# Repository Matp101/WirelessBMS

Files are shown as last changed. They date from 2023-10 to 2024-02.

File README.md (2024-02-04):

# WirelessBMS

## Project Overview

The Wireless Battery Management System (BMS) is engineered to provide comprehensive monitoring and management of battery cells for electric vehicles (EVs), energy storage systems, and other applications requiring detailed battery oversight. It boasts features such as cell voltage and temperature monitoring, advanced balancing algorithms, state of charge (SOC) estimation, and robust communication capabilities for seamless integration with broader system architectures. The system utilizes an ESP32 module for the parent unit to leverage its powerful processing capabilities and connectivity options, and ESP8266 modules for child units to efficiently handle specific tasks and communicate with the parent unit.

### Features

- **Real-Time Monitoring**: Continuous measurement of voltage and temperature parameters for each cell.
- **Data Logging**: The system records detailed logs on an SD card for analysis and record-keeping.
- **Overcharge Protection**: The circuitry is designed to prevent cells from overcharging, a critical safety feature.
- **Mesh Networking**: Parent and child units communicate over a mesh network, enhancing reliability and range.
- **User Interface**: An website that shows key information for immediate visual feedback.
- **Expandability**: This design allows for the addition of more child units to the network as needed.

### Hardware Components

- **Parent Unit**:
  - **Microcontroller**: ESP32 module for processing and network connectivity.
  - **Sensors**: Current sensor (ACS712), voltage divider components for voltage sensing.
  - **Protection**: Overcharge protection circuitry.
  - **Communication**: WiFi mesh networking.
  - **Storage**: SD card slot for data logging and retrieval.
  - **Power Supply**: Voltage regulator and battery input connectors.
  - **PCB**: Parent PCB design for mounting and connecting all components.
  
- **Child Units**:
  - **Microcontroller**: ESP8266 for individual cell monitoring tasks.
  - **Sensors**: Dedicated voltage for precise monitoring.
  - **PCB**: Child PCB design tailored to fit and function within a distributed system.

### Installation

1. **Environment Setup**: Use PlatformIO for firmware development. It provides a comprehensive ecosystem for IoT development.
2. **Board Assembly**: Refer to the Bill of Materials (BOM) and PCB design files to assemble the boards.
3. **Firmware Flashing**: Use PlatformIO to compile and upload the firmware to the ESP32 and ESP8266 modules.

### Configuration

 - **Basic Configuration**: The config.h file outlines essential settings, including communication protocols, number of cells monitored, voltage thresholds, and temperature limits.
 - **Advanced Configuration**: For further customization, adv_config.h provides options for fine-tuning balancing thresholds, SOC calculation parameters, and enhanced communication settings.
 - **Battery Configuration**: Specific battery types and their parameters, such as capacity and nominal voltage, are defined within batteries.h.
 - **Sensor Calibration**: Adjust the sensor readings according to the specific characteristics of the used components to ensure accurate measurements.

### Usage

 - **Monitoring**: Utilizes the ESP32 and ESP8266 modules to continuously monitor cell voltages and temperatures, displaying this data via a user interface or transmitting it over a network.
 - **Balancing**: Implements cell balancing through balance.hpp, applying algorithms to maintain uniform charge levels across all cells, which is crucial for maximizing battery lifespan and efficiency.
 - **SOC Estimation**: Leverages fuelgauge.hpp for accurate estimation of the battery's State of Charge, employing algorithms adapted to the battery's specific configuration for precise monitoring and management.
  
### Documentation

- **Schematics**: Detailed schematics are provided for both parent and child units to assist in understanding and modifying the circuitry.
- **PCB Designs**: PCB layout files are included for reproduction or customization of the boards.
- **BOM**: The Bill of Materials lists all components needed for assembly.

### Gallery
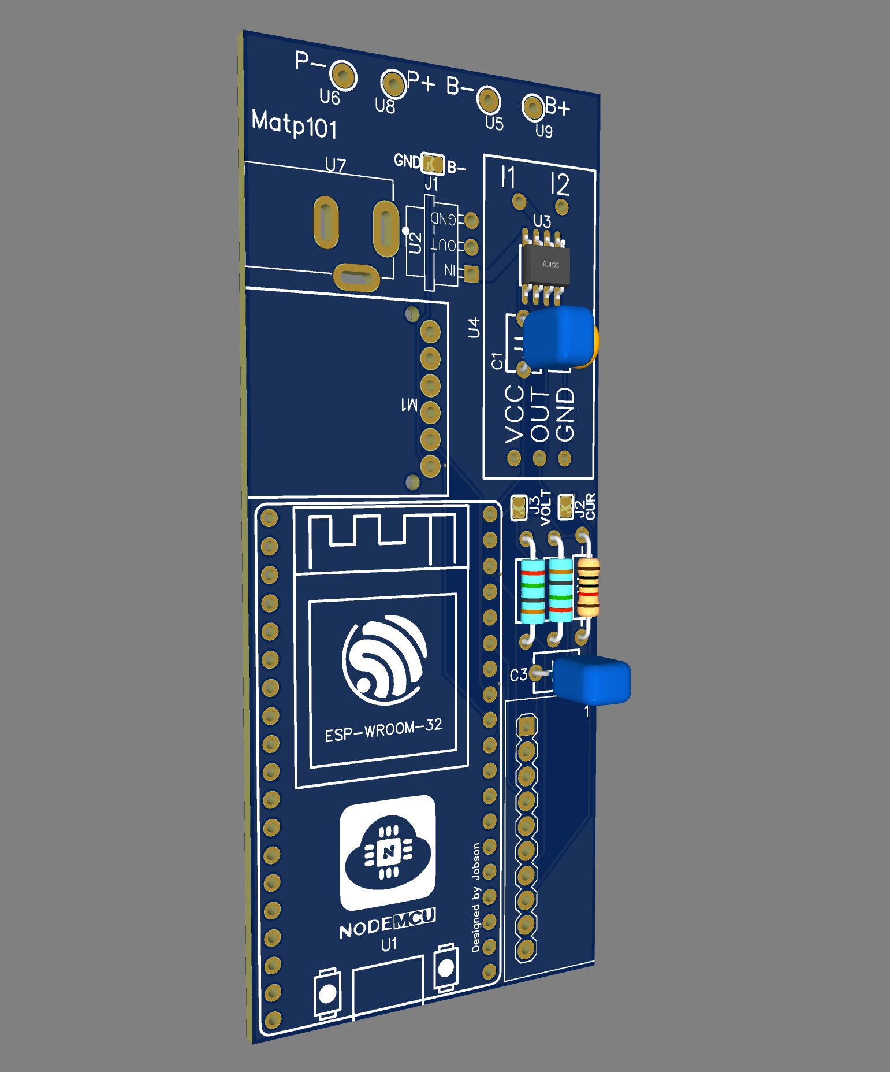
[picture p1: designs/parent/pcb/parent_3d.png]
Parent Unit

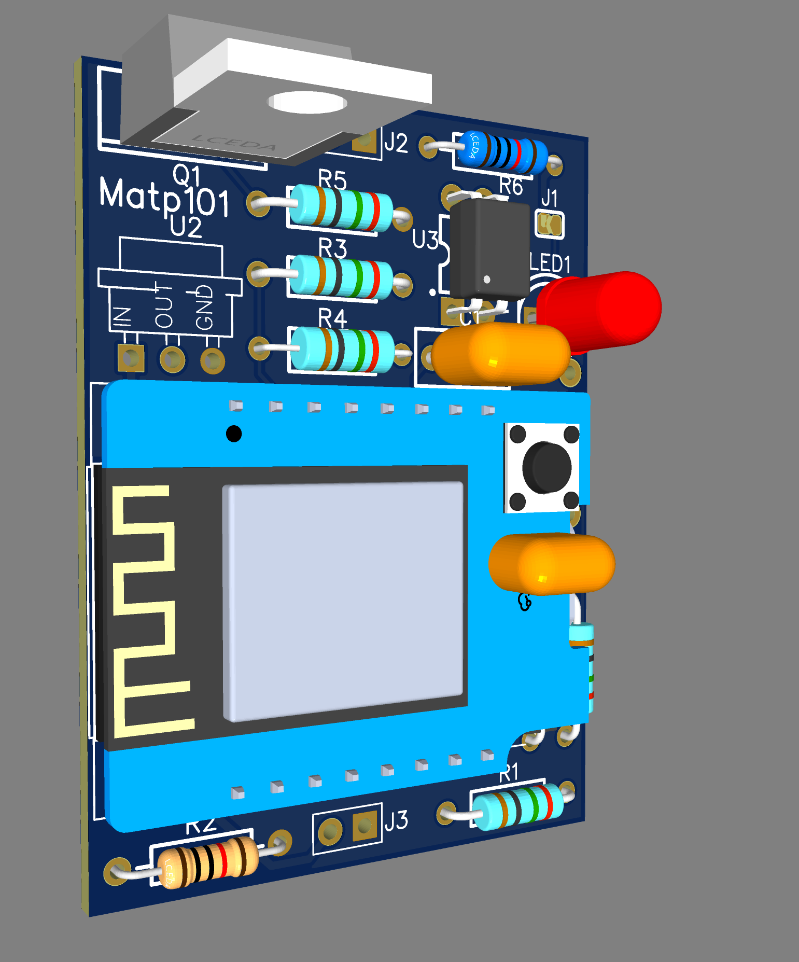
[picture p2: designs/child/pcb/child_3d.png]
Child Unit

Demo

---
## License

This work is licensed under the Creative Commons Attribution-NonCommercial-NoDerivs 4.0 International License. To view a copy of this license, visit [http://creativecommons.org/licenses/by-nc-nd/4.0/](https://creativecommons.org/licenses/by-nc-nd/4.0/) or send a letter to Creative Commons, PO Box 1866, Mountain View, CA 94042, USA.

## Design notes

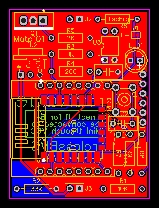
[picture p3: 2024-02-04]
designs/child/pcb/child_pcb.png

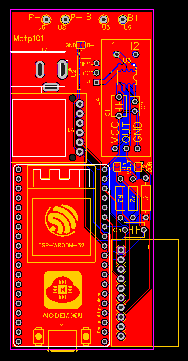
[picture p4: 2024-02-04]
designs/parent/pcb/parent_PCB.png

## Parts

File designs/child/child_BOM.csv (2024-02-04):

ID | Name | Designator | Footprint | Quantity | Manufacturer Part | Manufacturer | Supplier | Supplier Part | Price | Pins
1 | 100nF | C1,C2 | CAP-TH_L7.6-W3.8-P5.08-D0.51 | 2 | SR305C105KAR | Kyocera AVX | LCSC | C444741 | 0.629 | 2
2 | SOLDERJUMPERSMALL | J1 | SOLDERJUMPERSMALL | 1 |  |  |  |  |  | 2
3 | NO | J2,J3 | CONNECTOR_PINHEADER_2.54MM:PINHEADER_1X11_P_2.54MM | 2 | Female headerHDR1X8-2.54 | BOOMELE | LCSC | C27438 | 0.074 | 2
4 | FTDI | JP1 | FTDI | 1 |  |  |  |  |  | 6
5 | RESET | KEY1 | KEY-TH_4P-L6.0-W6.0-P4.50-LS7.5 | 1 | button6*6*8 | ReliaPro | LCSC | C59982 |  | 4
6 | LED-TH-3MM_R | LED1 | LED-TH_BD5.4-P2.54-FD_RED | 1 | LED-TH-3mm_R | null | LCSC | C9900003210 |  | 2
7 | IRLZ44PBF | Q1 | TO-220AB-3_L10.4-W4.6-P2.54-L | 1 | IRLZ44PBF-VB | VBsemi(微碧) | LCSC | C2680731 | 0.517 | 3
8 | 3.3kΩ | R1 | RES-TH_BD2.4-L6.3-P10.30-D0.6 | 1 | MFR-25FTE52-33K | YAGEO(国巨) | LCSC | C173005 | 0.012 | 2
9 | 10kΩ | R2 | RES-TH_BD2.2-L6.5-P10.50-D0.6 | 1 | MFR-25FTE52-100K | YAGEO(国巨) | LCSC | C172965 | 0.011 | 2
10 | 1kΩ | R3 | RES-TH_BD2.4-L6.3-P10.30-D0.6 | 1 | MFR50SFTE52-1K | YAGEO(国巨) | LCSC | C173143 | 0.02 | 2
11 | 200Ω | R4 | RES-TH_BD2.7-L6.2-P10.20-D0.4 | 1 | CR1/4W-200Ω±5%-ST52 | VO(翔胜) | LCSC | C2894669 | 0.003 | 2
12 | 2kΩ | R5 | RES-TH_BD2.4-L6.3-P10.30-D0.6 | 1 | MFR-25FTE52-2K | YAGEO(国巨) | LCSC | C172996 | 0.012 | 2
13 | 18Ω | R6 | RES-TH_BD2.3-L6.5-P10.50-D0.5 | 1 | CF1/4W-18Ω±5% T | CCO(千志电子) | LCSC | C120013 | 0.005 | 2
14 | 10kΩ | R7,R8,R9 | RES-TH_BD2.4-L6.3-P10.30-D0.6 | 3 | MFR-25FTE52-33K | YAGEO(国巨) | LCSC | C173005 | 0.012 | 2
15 | WEMOS_D1_MINI_PRO4 | U1 | DIP-16_WEMOS_D1_MINI_PRO4 | 1 | Wemos_D1_mini_Pro4 | null | LCSC | C2837266 |  | 16
16 | REG-AMS1117-3P-*#V | U2 | REG-AMS1117-3P#V | 1 |  |  |  |  |  | 3
17 | CYPC817D | U3 | DIP-4_L6.4-W4.6-P2.54-LS7.6-BL | 1 | CYPC817D | OCIC(卓睿科) | LCSC | C3018787 | 0.039 | 4
18 | ESP8266 | U4 | WIFIM-SMD_ESP-12F-ESP8266MOD | 1 | ESP8266 | null | LCSC | C9900003049 |  | 22

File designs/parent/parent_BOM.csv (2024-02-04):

ID | Name | Designator | Footprint | Quantity | Manufacturer Part | Manufacturer | Supplier | Supplier Part | Price | Pins
1 | ADC-4CH-ADS1115 | 1 | ADC-4CH-ADS1115 | 1 |  |  |  |  |  | 10
2 | 1nF | C1,C3 | CAP-TH_L5.5-W4.0-P5.00-D0.5 | 2 | Y5P102K2KV16CC0224 | KNSCHA(科尼盛) | LCSC | C2887266 | 0.034 | 2
3 | 100nF | C2 | CAP-TH_L5.0-W2.5-P2.54-D0.7 | 1 | CC1H104ZA1PD3F5O30MF | Dersonic(德尔创) | LCSC | C254067 | 0.02 | 2
4 | B- to GND | J1 | SOLDERJUMPERSMALL | 1 |  |  |  |  |  | 2
5 | A1 Connect | J2 | SOLDERJUMPERSMALL | 1 |  |  |  |  |  | 2
6 | A0 Connect | J3 | SOLDERJUMPERSMALL | 1 |  |  |  |  |  | 2
7 | MICRO-SD W 3D | M1 | MICRO-SD-MODULE | 1 |  |  |  |  |  | 6
8 | 10kΩ | R1 | RES-TH_BD2.2-L6.5-P10.50-D0.6 | 1 | MFR-25FTE52-100K | YAGEO(国巨) | LCSC | C172965 | 0.011 | 2
9 | 270kΩ | R2 | RES-TH_BD2.4-L6.3-P10.30-D0.6 | 1 | CFR-25JR-52-270K | YAGEO(国巨) | LCSC | C723609 | 0.006 | 2
10 | 160kΩ | R3 | RES-TH_BD2.4-L6.3-P10.30-D0.6 | 1 | CFR-25JR-52-270K | YAGEO(国巨) | LCSC | C723609 | 0.006 | 2
11 | NODEMCU-32SLUA | U1 | COMM-TH_NODEMCU-32SLUA | 1 | NodeMCU-32SLua | Ai-Thinker(安信可) | LCSC | C111436 |  | 38
12 | REG-AMS1117-3P-*#V | U2 | REG-AMS1117-3P#V | 1 |  |  |  |  |  | 3
13 | ACS712ELCTR-30A-T | U3 | SOIC-8_L5.0-W4.0-P1.27-LS6.0-BL | 1 | ACS712ELCTR-30A-T | ALLEGRO(美国埃戈罗) | LCSC | C9932 | 2.029 | 8
14 | ACS712AA | U4 | ACS712 | 1 |  |  |  |  |  | 5
15 | B- | U5 | 22-GAUGE | 1 |  |  |  |  |  | 1
16 | P- | U6 | 22-GAUGE | 1 |  |  |  |  |  | 1
17 | BARREL CONNECTOR | U7 | BARREL CONNECTOR | 1 |  |  |  |  |  | 3
18 | P+ | U8 | 22-GAUGE | 1 |  |  |  |  |  | 1
19 | B+ | U9 | 22-GAUGE | 1 |  |  |  |  |  | 1

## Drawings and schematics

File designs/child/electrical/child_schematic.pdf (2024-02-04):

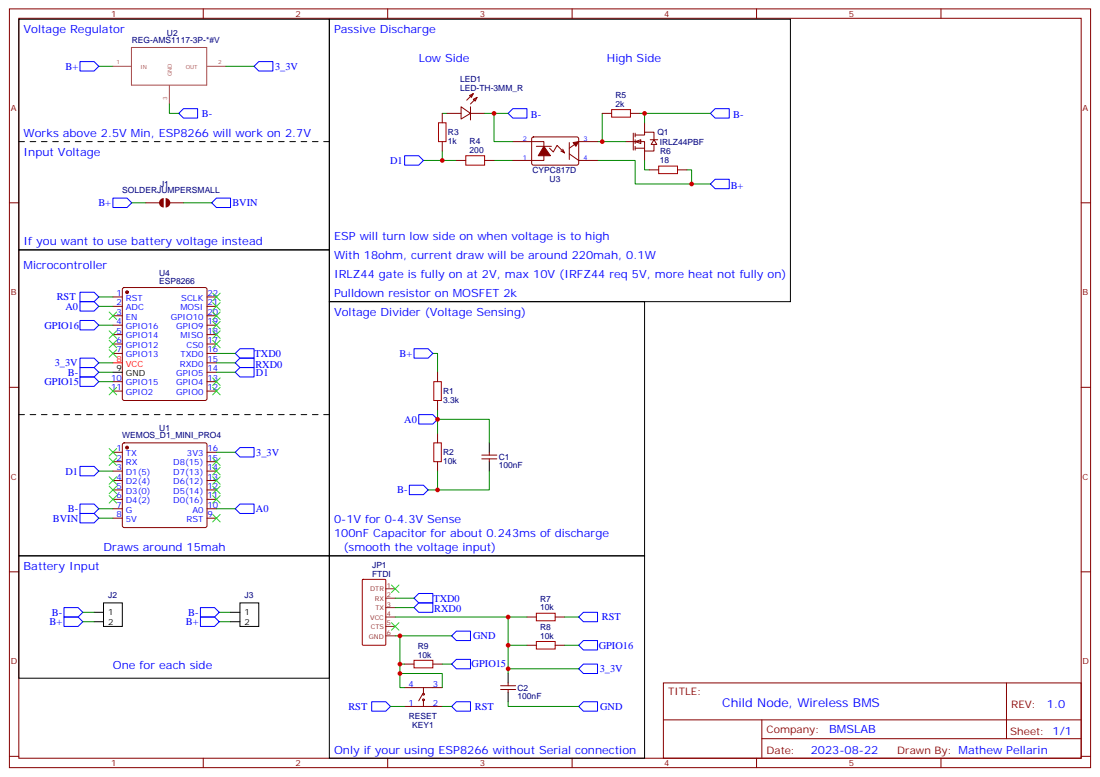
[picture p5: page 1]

Works above 2.5V Min, ESP8266 will work on 2.7V
Input Voltage

If you want to use battery voltage instead
Microcontroller

ESP will turn low side on when voltage is to high
With 18ohm, current draw will be around 220mah, 0.1W
IRLZ44 gate is fully on at 2V, max 10V (IRFZ44 req 5V, more heat not fully on)
Pulldown resistor on MOSFET 2k
Voltage Divider (Voltage Sensing)

One for each side

Only if your using ESP8266 without Serial connection

Drawn By: Mathew Pellarin

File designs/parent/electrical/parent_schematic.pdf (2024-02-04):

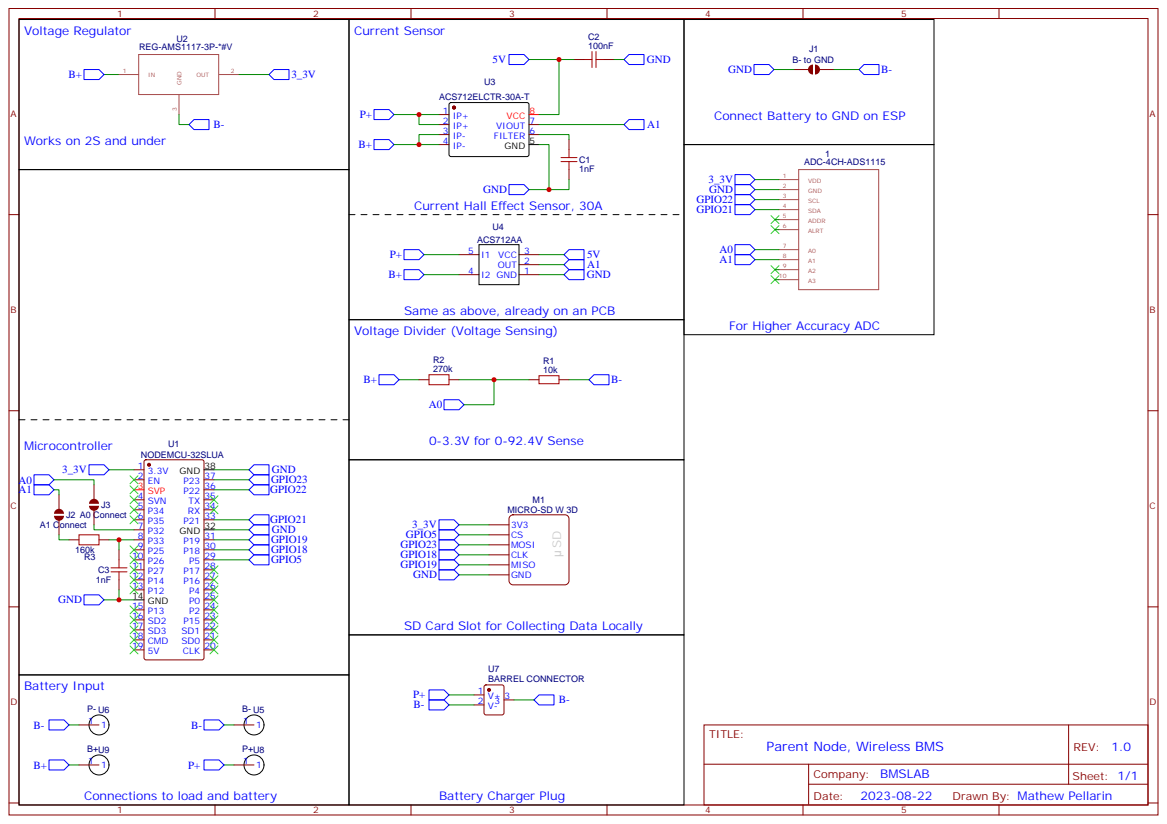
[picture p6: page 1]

Works on 2S and under

Connect Battery to GND on ESP

Current Hall Effect Sensor, 30A

Same as above, already on an PCB

For Higher Accuracy ADC

Voltage Divider (Voltage Sensing)

SD Card Slot for Collecting Data Locally

Connections to load and battery

Drawn By: Mathew Pellarin

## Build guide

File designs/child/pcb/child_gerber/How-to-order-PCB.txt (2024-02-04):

How to Order PCB

Please refer to:
https://docs.easyeda.com/en/PCB/Order-PCB

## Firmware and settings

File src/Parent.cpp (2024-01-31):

// TODO:
//  Add on connection, set cell number (save node_id to eeprom, save calibration)
//  SDcard logging
//  https://randomnerdtutorials.com/esp32-microsd-card-arduino/

#ifdef PARENT
#include <Arduino.h>
#include <painlessMesh.h>
#include <ArduinoJson.h>
#include <ACS712.h>
#include <ESPAsyncWebServer.h>
#include <fuelgauge.hpp>

#include <SPI.h>
#include <SD.h>

#include "batteries.h"
#include "config.h"
#include "adv_config.h"

#if defined(DEBUG_SERIAL) && !defined(PRINTF)
#define PRINTF(...)             \
  {                             \
    Serial.printf(__VA_ARGS__); \
  }
#endif
#if defined(DEBUG_LED) && defined(LED_BUILTIN)
#define LED LED_BUILTIN
#endif

// Parent 
struct Parent
{
  float voltage;
  float voltage_nodes;
  float current;
  float soc;
  float tt;
};

// Prototypes
void sendMessage();
void receivedCallback(uint32_t from, String &msg);
void newConnectionCallback(uint32_t nodeId);
void changedConnectionCallback();
void nodeTimeAdjustedCallback(int32_t offset);
void delayReceivedCallback(uint32_t from, int32_t delay);
float getVoltageNodes();
float getVoltageRead();
float getCurrent();
float getSOC();
float getTT();
int calibrateCurrent();
void updateValues();
void webserver();

Parent parent;

Scheduler userScheduler; // to control your personal task
painlessMesh mesh;

bool calc_delay = false;
SimpleList<uint32_t> nodes;

IPAddress getlocalIP();
AsyncWebServer server(80);
IPAddress myAPIP(IP_ADDRESS);

ACS712 current_sensor(CURRENT_SENSOR_TYPE, CURRENT_SENSOR_PIN, 3.3, 4095);
FuelGauge fuel_gauge(BATTERY_NOMINAL_CAPACITY, BATTERY_INTERNAL_RESISTANCE, BATTERY_MAX_VOLTAGE, BATTERY_LOAD_CURRENT, 4);

std::map<uint32_t, String> nodeData; // NodeID -> JSON data

bool fuel_gauge_initialized = false;

#ifdef DEBUG_LED
// Task to blink the number of nodes
Task blinkNoNodes;
bool onFlag = false;
#endif

void setup()
{
  Serial.begin(115200);
#ifdef DEBUG_LED
  pinMode(LED, OUTPUT);
#endif

  // setup wifi mesh
  mesh.setDebugMsgTypes(ERROR | STARTUP | DEBUG);
  mesh.init(MESH_SSID, MESH_PASSWORD, &userScheduler, MESH_PORT, WIFI_AP_STA, 6);
  mesh.onReceive(&receivedCallback);

  mesh.stationManual(STATION_SSID, STATION_PASSWORD);
  mesh.setHostname(HOSTNAME);

  mesh.onNewConnection(&newConnectionCallback);
  mesh.onChangedConnections(&changedConnectionCallback);
  mesh.onNodeTimeAdjusted(&nodeTimeAdjustedCallback);
  mesh.onNodeDelayReceived(&delayReceivedCallback);
  mesh.setRoot(true);
  mesh.setContainsRoot(true);

  myAPIP = IPAddress(mesh.getAPIP());
  PRINTF("My API IP is %d.%d.%d.%d\n", myAPIP[0], myAPIP[1], myAPIP[2], myAPIP[3]);

  // userScheduler.addTask( taskSendMessage );
  // taskSendMessage.enable();

#ifdef DEBUG_LED
  blinkNoNodes.set(BLINK_PERIOD, (mesh.getNodeList().size() + 1) * 2, []()
                   {
      // If on, switch off, else switch on
      if (onFlag)
        onFlag = false;
      else
        onFlag = true;
      blinkNoNodes.delay(BLINK_DURATION);

      if (blinkNoNodes.isLastIteration()) {
        // Finished blinking. Reset task for next run 
        // blink number of nodes (including this node) times
        blinkNoNodes.setIterations((mesh.getNodeList().size() + 1) * 2);
        // Calculate delay based on current mesh time and BLINK_PERIOD
        // This results in blinks between nodes being synced
        blinkNoNodes.enableDelayed(BLINK_PERIOD - 
            (mesh.getNodeTime() % (BLINK_PERIOD*1000))/1000);
      } });
  userScheduler.addTask(blinkNoNodes);
  blinkNoNodes.enable();

  PRINTF("Starting Webserver")
  webserver();
  server.begin();

#endif

}


static unsigned long lastUpdate = 0;
void loop()
{
  // mesh connected
  mesh.update();

  if(!fuel_gauge_initialized && getCurrent() == 0.0f){
    PRINTF("Initializing Fuel Gauge\n");
    fuel_gauge.initialize(getCurrent(), getVoltageNodes(), &parent.soc, &parent.tt);
    fuel_gauge_initialized = true;
  }

  //update current, voltage, soc, tt
  if (millis() - lastUpdate > 1000)
  {
    lastUpdate = millis();
    updateValues();
  }

  // Send JSON to Serial
  #ifdef JSON_SERIAL
  if (millis() - lastUpdate > JSON_SERIAL_INTERVAL)
  {
    lastUpdate = millis();
    PRINTF(toJson().c_str());
  }
  #endif

  // Blink LED if mesh is connected
#ifdef DEBUG_LED
  digitalWrite(LED, !onFlag);
#endif
}

// Send back to main node all the details about itself, if main node yet then broadcast
/*
If main esp is talking to this node
 info:cell == 0
 info:node_id == NodeId
 set:callibration_offset == int
 set:callibration_scale == int
 set:cell == int
 set:balance == bool
*/
void sendMessage()
{
  DynamicJsonDocument doc(256);
  doc["info"]["serial_number"] = SERIAL_NUMBER;
  doc["info"]["cell"] = 0;
  // doc["info"]["node_id"] =

  String jsonString;
  serializeJson(doc, jsonString);

  mesh.sendBroadcast(jsonString);
  // mesh.sendSingle(node, jsonString);
  if (calc_delay)
  {
    SimpleList<uint32_t>::iterator node = nodes.begin();
    while (node != nodes.end())
    {
      mesh.startDelayMeas(*node);
      node++;
    }
    calc_delay = false;
  }

#if DEBUG_SERIAL >= 1
  PRINTF("Sending message: %s\n", jsonString.c_str());
#endif
}

/*
  doc["info"]["serial_number"] = SERIAL_NUMBER;
  doc["info"]["cell"] = cell_num;
  doc["info"]["node_id"] = mesh.getNodeId();
  doc["info"]["free_mem"] = ESP.getFreeHeap();
  doc["cell"]["voltage"] = cell_voltage.getLastVoltage();   // make sure to get last voltage rather than update current due to passive balancing
  doc["cell"]["voltage_raw"] = cell_voltage.readRaw();
  doc["cell"]["voltage_calibration_offset"] = cell_voltage.getCalibrationOffset();
  doc["cell"]["voltage_calibration_scale"] = cell_voltage.getCalibrationScale();
  doc["balance"]["state"] = balancSer.getState();
*/
void receivedCallback(uint32_t from, String &msg)
{

#if DEBUG_SERIAL >= 2
  PRINTF("Received from %u msg=%s\n", from, msg.c_str());
#endif
  nodeData[from] = msg;
}

void newConnectionCallback(uint32_t nodeId)
{
#ifdef DEBUG_LED
  // Reset blink task
  onFlag = false;
  blinkNoNodes.setIterations((mesh.getNodeList().size() + 1) * 2);
  blinkNoNodes.enableDelayed(BLINK_PERIOD - (mesh.getNodeTime() % (BLINK_PERIOD * 1000)) / 1000);
#endif

#if DEBUG_SERIAL >= 1
  PRINTF("=================\nNew Connection\n");
  PRINTF("nodeId = %u\n", nodeId);
  PRINTF("%s\n", mesh.subConnectionJson(true).c_str());
  PRINTF("=================\n");
#endif
}

void changedConnectionCallback()
{

  nodes = mesh.getNodeList();

#ifdef DEBUG_LED
  // Reset blink task
  onFlag = false;
  blinkNoNodes.setIterations((mesh.getNodeList().size() + 1) * 2);
  blinkNoNodes.enableDelayed(BLINK_PERIOD - (mesh.getNodeTime() % (BLINK_PERIOD * 1000)) / 1000);
#endif

#if DEBUG_SERIAL >= 1
  // List all nodes
  PRINTF("=================\nChanged connections\n");
  PRINTF("Num nodes: %d\n", nodes.size());
  PRINTF("Connection list:");

  SimpleList<uint32_t>::iterator node = nodes.begin();
  while (node != nodes.end())
  {
    PRINTF(" %u", *node);
    node++;
  }
  PRINTF("\n=================\n");
#endif

  calc_delay = true;
}

void nodeTimeAdjustedCallback(int32_t offset)
{
#if DEBUG_SERIAL >= 1
  PRINTF("Adjusted time %u. Offset = %d\n", mesh.getNodeTime(), offset);
#endif
}

void delayReceivedCallback(uint32_t from, int32_t delay)
{
#if DEBUG_SERIAL >= 1
  PRINTF("Delay to node %u is %d us\n", from, delay);
#endif
}

float getVoltageNodes(){
  parent.voltage_nodes = 0.0f;
  for (auto &node : nodeData){
    //deserialize json and get voltage and add them all
    DynamicJsonDocument doc(256);
    deserializeJson(doc, node.second);
    parent.voltage_nodes += doc["cell"]["v"].as<float>();
  }
  return parent.voltage_nodes;
}

//TODO
float getVoltageRead(){
  parent.voltage = 0.0f;
  return parent.voltage;
}

float getCurrent(){
  parent.current = current_sensor.getDC();
  return parent.current;
}

float getSOC(){
  parent.soc = fuel_gauge.getSOC();
  return parent.soc;
}

float getTT(){
  parent.tt = fuel_gauge.getTTS();
  return parent.tt;
}

int calibrateCurrent(){
  fuel_gauge.initialize(0.0f, getVoltageNodes(), &parent.soc, &parent.tt);
  fuel_gauge_initialized = true;
  return current_sensor.autoCalibrate();
}

void updateValues(){
  parent.voltage = getVoltageRead();
  parent.voltage_nodes = getVoltageNodes();
  parent.current = getCurrent();
  if(fuel_gauge_initialized){
    //negate current
    float currentdraw = -parent.current;
    fuel_gauge.update(currentdraw, &parent.soc, &parent.tt);
  }
  //String out = "V:" + String(parent.voltage) + " VN:" + String(parent.voltage_nodes) + " C:" + String(parent.current) + " SOC:" + String(parent.soc) + " TT:" + String(parent.tt) + "\n";
  //PRINTF(out.c_str())
}

//==========================================================================================

const PROGMEM char* WEBSITE_HTML = R"html(
<html>
<head>
    <title>Wireless BMS</title>
    <style>
        table,
        th,
        td {
            border: 1px solid black;
            border-collapse: collapse;
        }

        p {
            margin: 0px;
        }
    </style>
</head>

<body>
    <div id="sd-color" style="width: 100%; height: 20px; background-color: red;">
        <p style="text-align: center; justify-content: center;">Not currently writing to sd output</p>
    </div>
    <div>
        <br>
        <label for="interval">Update interval (seconds):</label>
        <input type="number" id="interval" min="1" value="5">
    </div>
    <div id="parent">
        <h2>Parent</h2>
        <table cellpadding="5">
            <thead>
                <tr>
                    <th><strong>Voltage (V)</strong></th>
                    <th><strong>Voltage Nodes (V)</strong></th>
                    <th><strong>Discharge Current (A)</strong></th>
                    <th><strong>SOC (%)</strong></th>
                    <th><strong>TTS (h)</strong></th>
                    </tr>
                </thead>
                <tbody>
                    <tr>
                        <td id="p_v">0</td>
                        <td id="p_vn">0</td>
                        <td id="p_c">0</td>
                        <td id="p_s">0</td>
                        <td id="p_tt">0</td>
                    </tr>
                </tbody>
            </table>
            <br>

            <div id="calibrate" style="display: block ruby;">
                <button id="calibratebutton" class="button" onclick="calibrateCurrent()">Calibrate</button>
                <p id="calibrate-status">Calibrate Current. When calibrating, make sure <strong>NO</strong> load is outputing</p>
            </div>
    
            <br>
            <div id="sd" style="display: block ruby;">
                <button id="sdbutton" class="button" onclick="toggleSDwrite()">SD Card write</button>
                <p id="sd-status">SD card not found</p>
            </div>
        </div>
    
        <div id="nodes-info">
            <h2>Nodes</h2>
            <table cellpadding="5">
                <thead>
                    <tr>
                        <th>Cell</th>
                        <th>ID</th>
                        <th>SN</th>
                        <th>Voltage (V)</th>
                        <th>Voltage Raw</th>
                        <th>Balance State</th>
                        <th>Calibration Offset</th>
                        <th>Calibration Scale</th>
                        <th>Free Heap Memory</th>
                        <th>Actions</th>
                    </tr>
                </thead>
                <tbody id="nodes-table"></tbody>
            </table>
        </div>
    

            <script>
                let isEditing = false;

                function updateNodesTable(nodes) {
                    if (isEditing) return;

                    nodes.sort((a, b) => a.info.cell - b.info.cell);
                    let tableContent = '';
                    nodes.forEach(node => {
                        tableContent += `<tr id="row${node.info.id}">
		            <td>
						<p id="cell-${node.info.id}">${node.info.cell}</p>
		            	<input type="number" value="${node.info.cell}" id="cell-edit-${node.info.id}" style="display:none"/>
					</td>
		            <td>${node.info.id}</td>
		            <td>${node.info.sn}</td>
		            <td>${node.cell.v}</td>
		            <td>${node.cell.v_raw}</td>
		            <td>${node.bal.state}</td>
		            <td>
						<p id="offset-${node.info.id}">${node.cell.cal_offset}</p>
						<input type="number" value="${node.cell.cal_offset}" id="offset-edit-${node.info.id}" style="display:none"/>
					</td>
		            <td>
						<p id="scale-${node.info.id}">${node.cell.cal_scale}</p>
						<input type="number" value="${node.cell.cal_scale}" id="scale-edit-${node.info.id}" style="display:none"/>
					</td>
		            <td>${node.info.free_mem}</td>
					<td>
                        <button id="edit-${node.info.id}" onclick="enableEditing(${node.info.id})">Edit</button>
                        <button id="submit-${node.info.id}" onclick="submitChanges(${node.info.id})" style="display:none;">Submit</button>
                        <button id="cancel-${node.info.id}" onclick="cancelEdit(${node.info.id})" style="display:none;">Cancel</button>
                    </td>
                </tr>`;
                    });
                    document.getElementById('nodes-table').innerHTML = tableContent;

                    updateParent();
                }

                function fetchNodesData() {
                    fetch('/getNodes')
                        .then(response => response.json())
                        .then(data => {
                            updateNodesTable(data.nodes);
                        });
                }

                function toggleSDwrite() {
                    fetch('/toggleSD')
                        .then(response => response.json())
                        .then(data => {
                            const sdDiv = document.getElementById('sd-color');
                            if (data.sdStatus) {
                                sdDiv.style.backgroundColor = 'green';
                                sdDiv.innerHTML = '<p style="text-align: center; justify-content: center;">Writing to sd output</p>';
                            } else {
                                sdDiv.style.backgroundColor = 'red';
                                sdDiv.innerHTML = '<p style="text-align: center; justify-content: center;">Not currently writing to sd output</p>';
                            }
                        });
                }

                // Fetch nodes data on page load
                window.onload = fetchNodesData;

                let currentInterval;

                document.getElementById('interval').addEventListener('change', function () {
                    // Clear the existing interval
                    if (currentInterval) {
                        clearInterval(currentInterval);
                    }

                    // Set the new interval based on the input value
                    const milliseconds = this.value * 1000;
                    currentInterval = setInterval(fetchNodesData, milliseconds);
                    console.log('changed to ' + document.getElementById('interval').value * 1000)
                });

                // Set the initial interval when the page loads
                currentInterval = setInterval(fetchNodesData, document.getElementById('interval').value * 1000);

                function submitChanges(nodeId) {
                    // 1. Grab the current values of the editable cells for a given node.
                    let cellValue = document.getElementById(`cell-edit-${nodeId}`).value;
                    let offsetValue = document.getElementById(`offset-edit-${nodeId}`).value;
                    let scaleValue = document.getElementById(`scale-edit-${nodeId}`).value;

                    // Construct the data payload to send
                    let data = {
                        set: {
                            node_id: nodeId,
                            cell: parseInt(cellValue),
                            callibration_offset: parseFloat(offsetValue),
                            callibration_scale: parseFloat(scaleValue)
                        }
                    };

                    // 2. Send those values to the server
                    fetch('/updateNode', {
                        method: 'POST',
                        headers: {
                            'Content-Type': 'application/json',
                        },
                        body: JSON.stringify(data),
                    })
                        .then(response => response.json())
                        .then(data => {
                            // Handle server response
                            console.log(data);
                        })
                        .catch((error) => {
                            console.error('Error:', error);
                        });

                    isEditing = false;
                    fetchNodesData();
                }


                function enableEditing(nodeId) {
                    isEditing = true;
                    let rowToEdit = document.getElementById(`row${nodeId}`);
                    let cells = rowToEdit.querySelectorAll("td");

                    document.getElementById(`edit-${nodeId}`).style.display = 'none';
                    document.getElementById(`submit-${nodeId}`).style.display = 'inline-block';
                    document.getElementById(`cancel-${nodeId}`).style.display = 'inline-block';

                    document.getElementById(`cell-edit-${nodeId}`).style.display = 'inline-block';
                    document.getElementById(`offset-edit-${nodeId}`).style.display = 'inline-block';
                    document.getElementById(`scale-edit-${nodeId}`).style.display = 'inline-block';
                    document.getElementById(`cell-${nodeId}`).style.display = 'none';
                    document.getElementById(`offset-${nodeId}`).style.display = 'none';
                    document.getElementById(`scale-${nodeId}`).style.display = 'none';
                }

                function cancelEdit(nodeId) {
                    isEditing = false;
                    let rowToEdit = document.getElementById(`row${nodeId}`);
                    let cells = rowToEdit.querySelectorAll("td");
                    fetchNodesData();  // Reloads original data
                    document.getElementById(`edit-${nodeId}`).style.display = 'inline-block';
                    document.getElementById(`submit-${nodeId}`).style.display = 'none';
                    document.getElementById(`cancel-${nodeId}`).style.display = 'none';
                }

                function updateParent() {
                    fetch('/parent')
                        .then(response => response.json())
                        .then(data => {
                            // Structure is {v: voltage, c: current, s: soc, vn: voltageNodes}
                            document.getElementById('p_v').textContent = data.v;
                            document.getElementById('p_vn').textContent = data.vn;
                            document.getElementById('p_c').textContent = data.c;
                            document.getElementById('p_s').textContent = data.s*100;
                            document.getElementById('p_tt').textContent = data.tt;
                        });
                }

                function calibrateCurrent() {
                    fetch('/calibrateCurrent');
                }
            </script>
</body>

</html>
)html";
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

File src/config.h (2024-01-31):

// Debug
#define DEBUG_SERIAL 1              // 0: off, 1: info, 2: debug
// LED
#define DEBUG_LED                   // Comment out to disable LED blinking
#define BLINK_PERIOD    3000        // milliseconds until cycle repeat
#define BLINK_DURATION  100         // milliseconds LED is on for

#define SERIAL_NUMBER 0x00000000    // 32-bit unsigned integer, 0x00000000 to 0xFFFFFFFF

// PARENT
#define MESH_SSID       "bms"       // Mesh network SSID
#define MESH_PASSWORD   "bmslab123" // Must be at least 8 characters long
#define MESH_PORT       5555        // Mesh port to use
#define CHANNEL         6           // Mesh channel to use
#define   STATION_SSID     "bmslab"
#define   STATION_PASSWORD "bmslabtester"
#define HOSTNAME "HTTP_BRIDGE"
#define IP_ADDRESS 4,3,2,1
// Current Sensor
#define CURRENT_SENSOR_PIN 34            // Pin to read the current sensor from
#define CURRENT_SENSOR_TYPE ACS712_30A // Type of current sensor, ACS712_05B, ACS712_20A, ACS712_30A
// SD Card (SD CARD must be in FAT32 format)
#define SD_CS_PIN 5                // Pin to use for SD card chip select
#define SD_MOSI_PIN 23              // Pin to use for SD card MOSI
#define SD_CLK_PIN 18               // Pin to use for SD card CLK
#define SD_MISO_PIN 19              // Pin to use for SD card MISO
// Update interval
#define UPDATE_INTERVAL 1           // seconds, how often update data
// JSON output to Serial
#define JSON_SERIAL 1               // 0: off, 1: on
#define JSON_SERIAL_INTERVAL 1000   // milliseconds, how often to send data

// CHILD
#define BALANCER_PIN 2              // Pin to control the balancer
#define BALANCER_INVERTED false     // Set to true if the balancer is active low
// Indvidual cell voltage 
#define BATTERY_VOLTAGE_PIN 0       // Pin to read the battery voltage from
#define BATTERY_VOLTAGE_MAX 4.2f    // Maximum voltage of the battery
#define BATTERY_MAX_THRESHOLD 0.05f // Battery has to fall below BATTERY_VOLTAGE_MAX minus this to turn off balancer
// Update interval
#define UPDATE_INTERVAL 1           // seconds, how often to send data
#define READ_VOLTAGE_INTERVAL 1     // seconds, how often to update the voltage
#define VOLTAGE_SETTLE_DELAY 5000   // milliseconds, how long to wait for voltage to settle once balancer is turned off 
// EEPROM
#define EEPROM_SIZE 128
#define EEPROM_START 0
// Information
int cell_num = 0;                   // cell number, 0-indexed

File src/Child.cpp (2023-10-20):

//TOOD: EEPROM for calibration values and cell number

//#define CHILD
#ifdef CHILD
#include <Arduino.h>
#include <painlessMesh.h>
#include <ArduinoJson.h>
#include <EEPROM.h>

#include "config.h"
#include "adv_config.h"
#include "voltage_divider.hpp"
#include "balance.hpp"


#if defined(DEBUG_SERIAL) && !defined(PRINTF) 
#define PRINTF(...) { Serial.printf(__VA_ARGS__); }
#endif
#if defined(DEBUG_LED) && defined(LED_BUILTIN)
#define LED LED_BUILTIN
#endif

struct EEPROM_Data{
  float version;
  int reserved1;
  int reserved2;
  int cell_number;
  float voltage_offset;
  float voltage_scale;
};


// Prototypes
void sendMessage(); 
void receivedCallback(uint32_t from, String & msg);
void newConnectionCallback(uint32_t nodeId);
void changedConnectionCallback(); 
void nodeTimeAdjustedCallback(int32_t offset); 
void delayReceivedCallback(uint32_t from, int32_t delay);
void readVoltageAsync();
void saveEEPROM();

Scheduler     userScheduler; // to control your personal task
painlessMesh  mesh;

bool calc_delay = false;
SimpleList<uint32_t> nodes;

Task taskSendMessage(TASK_SECOND * 1, TASK_FOREVER, &sendMessage ); // start with a one second interval

//Task taskReadVoltage(TASK_SECOND * 1, TASK_FOREVER, &readVoltageAsync);

#ifdef DEBUG_LED
// Task to blink the number of nodes
Task blinkNoNodes;
bool onFlag = false;
#endif

VoltageDivider cell_voltage(BATTERY_VOLTAGE_PIN, BATTERY_VOLTAGE_MAX, BATTERY_VOLTAGE_CALIBRATION_OFFSET, BATTERY_VOLTAGE_CALIBRATION_SCALE);
Balancer balancer(BALANCER_PIN, BALANCER_INVERTED);

uint32_t main_node = 0;

EEPROM_Data eeprom_data;

void setup() {
  Serial.begin(115200);

  EEPROM.begin(EEPROM_SIZE);
  EEPROM.get(EEPROM_START, eeprom_data);

  if(eeprom_data.version != VERSION){
    for(int i = 0; i < EEPROM_SIZE; i++){
      EEPROM.put(0, 0);
    }
    eeprom_data.voltage_offset = BATTERY_VOLTAGE_CALIBRATION_OFFSET;
    eeprom_data.voltage_scale = BATTERY_VOLTAGE_CALIBRATION_SCALE;
    eeprom_data.cell_number = 0;
    eeprom_data.version = VERSION;
  }

  cell_voltage.begin(eeprom_data.voltage_offset, eeprom_data.voltage_scale);
  cell_voltage.setAnalogClockDivider(ADC_CLOCK_DIV_16); //ONLY FOR ESP32

  balancer.begin();
  
#ifdef DEBUG_LED
  pinMode(LED, OUTPUT);
#endif

  //setup wifi mesh
  mesh.setDebugMsgTypes(ERROR | DEBUG);  // set before init() so that you can see error messages
	mesh.init(MESH_SSID, MESH_PASSWORD, &userScheduler, MESH_PORT, WIFI_AP_STA, CHANNEL);
  mesh.onReceive(&receivedCallback);
  mesh.onNewConnection(&newConnectionCallback);
  mesh.onChangedConnections(&changedConnectionCallback);
  mesh.onNodeTimeAdjusted(&nodeTimeAdjustedCallback);
  mesh.onNodeDelayReceived(&delayReceivedCallback);
  mesh.setContainsRoot(false);

  userScheduler.addTask( taskSendMessage );
  taskSendMessage.enable();

#ifdef DEBUG_LED
  blinkNoNodes.set(BLINK_PERIOD, (mesh.getNodeList().size() + 1) * 2, []() {
      // If on, switch off, else switch on
      if (onFlag)
        onFlag = false;
      else
        onFlag = true;
      blinkNoNodes.delay(BLINK_DURATION);

      if (blinkNoNodes.isLastIteration()) {
        // Finished blinking. Reset task for next run 
        // blink number of nodes (including this node) times
        blinkNoNodes.setIterations((mesh.getNodeList().size() + 1) * 2);
        // Calculate delay based on current mesh time and BLINK_PERIOD
        // This results in blinks between nodes being synced
        blinkNoNodes.enableDelayed(BLINK_PERIOD - 
            (mesh.getNodeTime() % (BLINK_PERIOD*1000))/1000);
      }
  });
  userScheduler.addTask(blinkNoNodes);
  blinkNoNodes.enable();
#endif
}

void loop() {
  // mesh connected
  mesh.update();

  // Read the battery voltage and turn on balancer if needed
  readVoltageAsync();

  //Blink LED if mesh is connected
#ifdef DEBUG_LED
  digitalWrite(LED, !onFlag);
#endif

}

bool isConnectedToAnyNode() {
    return !mesh.getNodeList().empty();
}

// Send back to main node all the details about itself, if main node yet then broadcast
void sendMessage() {
  if (!isConnectedToAnyNode() ) {  // Check if the device is connected
    return;  // If not connected, exit the function without sending
  }
  DynamicJsonDocument doc(256);
  doc["info"]["cell"] = cell_num;
  doc["info"]["id"] = mesh.getNodeId();
  doc["info"]["sn"] = SERIAL_NUMBER;
  doc["cell"]["v"] = cell_voltage.getLastVoltage();   // make sure to get last voltage rather than update current due to passive balancing
  doc["cell"]["v_raw"] = cell_voltage.readRaw();
  doc["bal"]["state"] = balancer.getState();
  doc["cell"]["cal_offset"] = cell_voltage.getCalibrationOffset();
  doc["cell"]["cal_scale"] = cell_voltage.getCalibrationScale();
  doc["info"]["free_mem"] = ESP.getFreeHeap();  
  String jsonString;
  serializeJson(doc, jsonString);  

  if (main_node == 0)
    mesh.sendBroadcast(jsonString);
  else
    mesh.sendSingle(main_node, jsonString);
  if (calc_delay) {
    SimpleList<uint32_t>::iterator node = nodes.begin();
    while (node != nodes.end()) {
      mesh.startDelayMeas(*node);
      node++;
    }
    calc_delay = false;
  }

#if DEBUG_SERIAL >= 1
  PRINTF("Sending message: %s\n", jsonString.c_str());
#endif
}

// If main esp is talking to this node
//  info:cell == 0
//  info:node_id == NodeId
//  set:cal_offset == int
//  set:cal_scale == int
//  set:cell == int
//  set:balance == bool
void receivedCallback(uint32_t from, String & msg) {

#if DEBUG_SERIAL >= 2
  PRINTF("Received from %u msg=%s\n", from, msg.c_str());
#endif

  if (from != main_node && main_node != 0)
    return;

  StaticJsonDocument<256> doc;
  DeserializationError error = deserializeJson(doc, msg);
  if (error) {
#if DEBUG_SERIAL >= 1
    PRINTF("deserializeJson() failed: %s\n", error.c_str());
#endif
    return;
  }

  if (main_node != 0){
    //Only talk to main esp and make sure values are present
    if (!doc.containsKey("info") && !doc["info"].containsKey("cell"))
      return;
    if (doc["info"]["cell"] != 0)
        return;
  
    main_node = from;
  }
  
  //if main esp is talking to this node
  if (!doc.containsKey("set")){
    PRINTF("ERROR: No set key\n")
    return;
  }
  if (!doc["set"].containsKey("id")) {
    PRINTF("ERROR: No id key\n")
    return;
  }
  if (doc["set"]["id"] != mesh.getNodeId()){
    PRINTF("ERROR: Not my id\n")
    return;
  }
  PRINTF("=== Changed Settings ===")

  bool changed_settings = false;
  //if main esp is talking to this node //set:cell:voltage_calibration_offset
  if (doc["set"].containsKey("cal_offset")){
    float offset = doc["set"]["cal_offset"].as<float>();
    bool flag = cell_voltage.setCalibrationOffset(offset);
    if (flag == true){
      changed_settings = true;
    }
#if DEBUG_SERIAL >= 2
    PRINTF("set cal offset: %f\n", offset)
#endif
  }
  if (doc["set"].containsKey("cal_scale")){
    float scale = doc["set"]["cal_scale"].as<float>();
    bool flag = cell_voltage.setCalibrationScale(scale);
    if (flag == true){
      changed_settings = true;
    }
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

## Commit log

2023-10-15 added Website and fixed bugs
    [ACS712.h, Master.cpp, Slave.cpp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]
2023-10-20 Added voltage and current readings
2024-02-04 Added Designs
    [Drill_NPTH_Through.DRL, Drill_PTH_Through.DRL, Drill_PTH_Through_Via.DRL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]
